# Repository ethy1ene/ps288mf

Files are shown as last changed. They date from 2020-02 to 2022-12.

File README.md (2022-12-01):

# PS288MF

A simple Arduino-based PS/2 to PC-8801F/M keyboard adapter.

PC-8801FH以降用のPS2キーボードアダプター 

Need PS2keyAdvanced library.

# Default pinout

|PS/2 keyboard|Arduino|PC-8801 host|
|:---:|:-----:| :---:|
|+5v|+5v|+5v|
| |D6|Rx|
|DATA|D4||
|CLK|D3||
|GND|GND|GND|

PC-88MA side pinout:

avatar

# Keymap

avatar

# Usage

Just buy a Arduino Nano, upload the codes, connect the cables as above. :)

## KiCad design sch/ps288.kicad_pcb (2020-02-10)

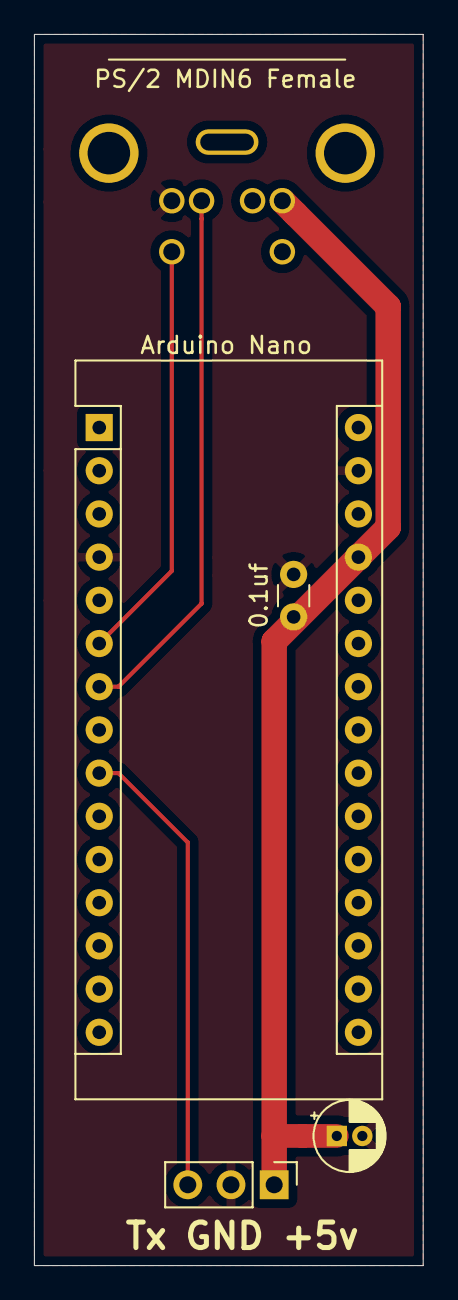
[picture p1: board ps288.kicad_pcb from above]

Board: 2 copper layers, 22.9 x 72.4 mm, 5 parts (0 on the bottom side), 5 nets.

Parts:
0.1uf: C; C_Disc_D3.0mm_W1.6mm_P2.50mm
A1: Arduino_Nano_v3.x; Arduino_Nano
C1: CP1; CP_Radial_D4.0mm_P1.50mm
J1: Mini-DIN-6; mdin6
J2: Conn_01x03_Female; PinHeader_1x03_P2.54mm_Vertical

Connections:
+5V: 0.1uf.1, A1.27, C1.1, J1.4, J2.1
GND: 0.1uf.2, A1.4, A1.29, C1.2, J1.3, J2.2
unnamed: A1.6, J1.5
unnamed: A1.7, J1.1
unnamed: A1.9, J2.3

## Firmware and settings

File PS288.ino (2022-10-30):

#include <avr/io.h>         //avr library for timer
#include <avr/interrupt.h>
#include <PS2KeyAdvanced.h> 
#define TXPIN 6             //pc88keyboard tx pin
#define DATAPIN 4           //ps2 data pin
#define IRQPIN  3           //ps2 clock pin
PS2KeyAdvanced keyboard;
uint16_t c,buff=0;
char a=0,p=0,brkflag=0;


const unsigned int K[120]={0xFFC0, 0xFFA0, 0xFF60, 0xFEE0, 0xFDE0, 0xFBE0, 0xF7E0, 0xEFE0,
                           0xDFC2, 0xDFA2, 0xDF62, 0xDEE2, 0xDDE2, 0xDBE2, 0xD7E2, 0xCFE2,
                           0xDFC4, 0xDFA4, 0xDF64, 0xDEE4, 0xDDE4, 0xDBE4, 0xD7E4, 0xCFE4,
                           0xFFC6, 0xFFA6, 0xFF66, 0xFEE6, 0xFDE6, 0xFBE6, 0xF7E6, 0xEFE6,
                           0xDFC8, 0xDFA8, 0xDF68, 0xDEE8, 0xDDE8, 0xDBE8, 0xD7E8, 0xCFE8,
                           0xFFCA, 0xFFAA, 0xFF6A, 0xFEEA, 0xFDEA, 0xFBEA, 0xF7EA, 0xEFEA,
                           0xFFCC, 0xFFAC, 0xFF6C, 0xFEEC, 0xFDEC, 0xFBEC, 0xF7EC, 0xEFEC,
                           0xDFCE, 0xDFAE, 0xDF6E, 0xDEEE, 0xDDEE, 0xDBEE, 0xD7EE, 0xCFEE,
                           0xDFD0, 0xDFB0, 0xDF70, 0xDEF0, 0xDDF0, 0xDBF0, 0xD7F0, 0xCFF0,
                           0xFFD2, 0xFFB2, 0xFF72, 0xFEF2, 0xFDF2, 0xFBF2, 0xF7F2, 0xEFF2,
                           0xFFD4, 0xFFB4, 0xFF74, 0xFEF4, 0xFDF4, 0xFBF4, 0xF7F4, 0xEFF4,
                           0xDFD6, 0xDFB6, 0xDF76, 0xDEF6, 0xDDF6, 0xDBF6, 0xD7F6, 0xCFF6,
                           0xFFD8, 0xFFB8, 0xFF78, 0xFEF8, 0xFDF8, 0xFBF8, 0xF7F8, 0xEFF8,
                           0xDFDA, 0xDFBA, 0xDF7A, 0xDEFA, 0xDDFA, 0xDBFA, 0xD7FA, 0xCFFA,
                           0xDFDC, 0xDFBC, 0xDF7C, 0xDEFC, 0xDDFC, 0xDBFC, 0xD7FC, 0xCFFC};   //pc88 code array


                           
const unsigned int KO[120]={0x20,  0x21,  0x22,  0x23,  0x24,  0x25,  0x26,  0x27,
                            0x28,  0x29,  0x2E,  0x2C,  0x5F,  0x3B,  0x3D,  0x11E,
                            0x2F,  0x41,  0x42,  0x43,  0x44,  0x45,  0x46,  0x47,
                            0x48,  0x49,  0x4A,  0x4B,  0x4C,  0x4D,  0x4E,  0x4F,
                            0x50,  0x51,  0x52,  0x53,  0x54,  0x55,  0x56,  0x57,
                            0x58,  0x59,  0x5A,  0x5D,  0x5C,  0x5E,  0x16C,  0x3C,
                            0x30,  0x31,  0x32,  0x33,  0x34,  0x35,  0x36,  0x37,
                            0x38,  0x39,  0x3A,  0x5B,  0x3B,  0x3D,  0x3E,  0x2D,
                            0x111, 0x117, 0x116, 0x104, 0x90A, 0x2109, 0x4106,  0x2108,
                            0x16B, 0x161, 0x162, 0x163, 0x164, 0x165, 0x11F, 0x11B,
                            0x11D, 0x118, 0x115, 0x30D, 0x10E, 0x3C,  0x3E,  0x1103,
                            0x113, 0x114, 0x30,  0x30,  0x30,  0x30,  0x30,  0x30,
                            0x166, 0x167, 0x168, 0x169, 0x16A, 0x11C, 0x119, 0x11A,
                            0x30C, 0x50B, 0x112, 0x40,  0x30,  0x30,  0x30,  0x30,
                            0x11E, 0x2B,  0x4106,  0x4107,  0x30,  0x30,  0x30,  0x30};       //ps2 code array



const unsigned int BRK[15]={0xDFE0, 0xFFE2 ,0xFFE4 ,0xDFE6 ,0xFFE8 ,0xDFEA ,0xDFEC ,0xFFEE ,
                            0xFFF0, 0xDFF2, 0xDFF4, 0xFFF6, 0xDFF8, 0xFFFA, 0xFFFC};                 //break code array



void SENDKEY(uint16_t data,char dl)       //key sending func
{
  a=0;
  buff=data;  //load keycode
  TCCR1A = 0;  // set Timer register to 0
  TCCR1B = 0;  
  OCR1A = 763;                          // 768 in theory,acutually 763 is the best
  TCCR1B |= (1 << WGM12);               // turn on CTC mode: 
  TIMSK1 |= (1 << OCIE1A);              // enable timer compare interrupt:
  TCCR1B |= (1 << CS10);                // Set  mode 
  while(a<16)                           //wait the sending finish
  {
    digitalWrite(LED_BUILTIN, HIGH);
  }
  TCCR1B &= ~(1 << CS10);    //stop the timer clock
  TIMSK1 &= ~(1 << OCIE1A);  //stop the timer interrupt
  digitalWrite(LED_BUILTIN, LOW);
  delay(dl);                 //slightly high input latency when fast typing,
                             //but codes with the same row number must be sent after 35ms , dont know why
}

ISR(TIMER1_COMPA_vect) //ISR func
{ 
  digitalWrite(TXPIN,bitRead(buff,a));//send 1bit
  a++;
}

void clean()
{
  SENDKEY(BRK[0],3);
  SENDKEY(BRK[1],3);
  SENDKEY(BRK[2],3);
  SENDKEY(BRK[3],3);
  SENDKEY(BRK[4],3);
  SENDKEY(BRK[5],3);
  SENDKEY(BRK[6],3);
  SENDKEY(BRK[7],3);
  SENDKEY(BRK[8],3);
  SENDKEY(BRK[9],3);
  SENDKEY(BRK[10],3);
  SENDKEY(BRK[11],3);
  SENDKEY(BRK[12],3);
  SENDKEY(BRK[13],3);
  SENDKEY(BRK[14],3);
}


void setup() {
  keyboard.begin( DATAPIN, IRQPIN );  //PS2Keyboard service
  pinMode(TXPIN,OUTPUT);              //Tx pin init
  digitalWrite(TXPIN, HIGH);
  clean();                    //reset fix freezing
}


void loop() {

  if( keyboard.available() )              //read when buffer available
  {
    c=keyboard.read();                    //read next code
    brkflag=bitRead(c,15);                //break code or not
    switch (brkflag)
    {
    case 0:                               //make code
    for (p=0;p<120;p++)
     {
      if ((c&0x00ff)==(KO[p]&0x00ff))     //code compare
      {
        if(p==102)                        //extend keys INS
        {
          SENDKEY(K[102],36);
          SENDKEY(K[70],36);
          SENDKEY(K[67],36);
        }
        else if (p<101&&p>95)             //extend keys F6-F10
        {
          SENDKEY(K[p],36);
          SENDKEY(K[70],36);
          SENDKEY(K[p-23],36);
        }
        else if (p==101||p==103)          //extend keys BS DEL
        {
          SENDKEY(K[p],36);
          SENDKEY(K[67],36);
        }
        else if (p==104||p==105)          //extend keys HENKAN KETTEI
        {
          SENDKEY(K[p],36);
          SENDKEY(K[78],36);
        }
        else if (p==112||p==113)          //extend keys RETURN RETURN(NUMPAD)
        {
          SENDKEY(K[p],36);
          SENDKEY(K[15],36);
        }
        else if (p==114||p==115)          //extend keys LSHIFT RSHIFT
        {
          SENDKEY(K[p],36);
          SENDKEY(K[70],36);
        }
        else 
        SENDKEY(K[p],36);     //normal keys
        break;
        }
     }
     break;
     case 1:                              //break code
     for (p=0;p<120;p++)
     {
      if ((c&0x00ff)==(KO[p]&0x00ff))     //same as make
      {
        
        if(p==102)
        {
          SENDKEY(BRK[12],36);
          SENDKEY(BRK[8],36);
          SENDKEY(BRK[8],36);
        }
        else if (p<101&&p>95)
        {
          SENDKEY(BRK[12],36);
          SENDKEY(BRK[9],36);
          SENDKEY(BRK[8],36);
        } 
        else if (p==101||p==103)
        {
          SENDKEY(BRK[12],36);
          SENDKEY(BRK[8],36);
        }
        else if (p==104||p==105)
        {
          SENDKEY(BRK[13],36);
          SENDKEY(BRK[9],36);
        }
        else if (p==112||p==113)
        {
          SENDKEY(BRK[14],36);
          SENDKEY(BRK[1],36);
        }
        else if (p==114||p==115)
        {
          SENDKEY(BRK[14],36);
          SENDKEY(BRK[8],36);
        }
        else
        SENDKEY(BRK[p/8],36);
        break;
        }
      }
    }
  }
}

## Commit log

2019-07-12 fix bugs
    fix some bugs , add more bugs.
    [PS288.ino]
2020-02-09 better timer and delay() value
2020-02-10 Add PCB files.
    [ps288.kicad_pcb, ps288.sch]
